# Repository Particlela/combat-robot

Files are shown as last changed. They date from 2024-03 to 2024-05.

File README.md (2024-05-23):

# combat-robot
# Robot_version_1.0
## 代码思路
基础运动底层模块写在move.c文件中(包含了对应函数)
巡线转弯等复杂模块写在game.c文件中
通过数组确定运动逻辑
该代码为电池电量较充足时可以较好地完成拿3分的任务,预赛因电量变化出现误差
### 灰度传感器
始终都要工作，通过gpio口发送信息给主板进行处理，以达到巡线目的
### 接口
PE7-11被设置为五个灰度传感器的信号输入(高电平1 低电平0)
PE7接R2 橙色
PE8接R1 黄色
PE9接M 绿色
PE10接L1 蓝色
PE11接L2 紫色
要接5V和GND接口供电

### 差速两轮驱动小车
用了定时器从模式，频率为10kHz，TIM2主 TIM3 TIM4从
#### 接口
PD2对应IN1(白色)  PD3对应IN2(灰色)  IN1高IN2低左电机正转反之反转
PD0对应IN3(紫色)  PD1对应IN4(蓝色)  IN3高IN4低右电机正转反之反转
PA6接通道A(黑色)  PD12接通道B(绿色)
右轮 棕色上黑色下
左轮 紫色上蓝色下

#### 调试
**读转速要让定时器进入编码器模式**
接5V GND(L298N) 两个GPIO口(两个轮子都要)
50是最低极限
巡航占空比为88
#### 转速
TIM1(左)和TIM8(右)开编码器模式
TIM6计时10ms,每10ms读一次数据，最后输出转速
520B编码器:绿接地 蓝接3.3V 黄白连在(暂时不知道顺序)

### 舵机控制钳子
控制舵机可以只使用一个PWM信号，因为两个舵机只需要相对角度确定即可(TIM9)
#### 接口
接两个5V(红色) GND(棕色) PE6(左黄色) PE5(右黄色)

### 看门狗
防止出现故障却停不下的问题
1s重启一次,需要一直喂狗,注意关注能否每1s内能够喂狗
version1.0中删除了这一功能,因为开发者未能很好的使看门狗达到预期效果

### 蓝牙模块
用于发送代码进行调试
用TIM5确保非阻塞运行,频率为1Hz
暂时无法使用
#### 接口
接板子上写了USART2的四个接口

### 串口
目前使用串口收发数据,每50ms发送一次信息

### 断电与供电
长按key0断电,reset重启
key1将在校赛中有新的规划

## 算法
运用数组确定运动逻辑
通过调参实际测试确定参数,保证巡线与转弯准度
暂未实现PID控制算法
暂未实现读取电机转速
暂未修改车底板及设计(初步想法为框住物块,这样在运动中同时打乱空心圆柱位置)

# Robot_version_2.0
# Robot
## 代码思路
基础运动底层模块写在move.c文件中(包含了对应函数) 巡线转弯等复杂模块写在game.c文件中 通过数组确定运动逻辑 该代码为电池电量较充足时可以较好地完成拿3分的任务,预赛因电量变化出现误差
### 灰度传感器
始终都要工作，通过gpio口发送信息给主板进行处理，以达到巡线目的
### 接口
PE7-11被设置为五个灰度传感器的信号输入(高电平1 低电平0)
PE7接R2 紫色
PE8接R1 蓝色
PE9接M 绿色
PE10接L1 黄色
PE11接L2 橙色
要接5V和GND接口供电

### 差速两轮驱动小车
用了定时器从模式，频率为10kHz，TIM2主 TIM3 TIM4从
#### 接口
PD2对应IN1(红色)  PD3对应IN2(橙色)  IN1高IN2低左电机正转反之反转
PD0对应IN3(黄色)  PD1对应IN4(绿色)  IN3高IN4低右电机正转反之反转
PA6接通道A(棕色)  PD12接通道B(蓝色)
右轮 棕色上黑色下
左轮 紫色上蓝色下

#### 调试
**读转速要让定时器进入编码器模式**
接5V GND(L298N) 两个GPIO口(两个轮子都要)
50是最低极限 巡航占空比为88

#### 转速
TIM1(左)和TIM8(右)开编码器模式
TIM6计时10ms,每10ms读一次数据，最后输出转速
520B编码器:绿接地 蓝接3.3V 本版本为连在无输出的接口

### 舵机控制钳子
控制舵机可以只使用一个PWM信号，因为两个舵机只需要相对角度确定即可(TIM9)
#### 接口
接两个5V(红色) GND(棕色) PE5(左黄色) PE6(右黄色)

### 蓝牙模块
用于发送代码进行调试
用TIM5确保非阻塞运行，频率为1Hz
#### 接口
接板子上写了USART2的那四个接口

### 串口
目前使用串口收发数据,每50ms发送一次信息

### 断电与供电
长按key0断电,reset重启 按下key1调整路径

## 算法
运用数组确定运动逻辑 通过调参实际测试确定参数,保证巡线与转弯准度
目前为二维数组，储存不同的路径
*(初步想法为框住物块,这样在运动中同时打乱空心圆柱位置)*
已修改，目前为框住物块并在万向轮前设有挡板

## 改进
姿态调整能否使用递归确保能够调整至理想状态，避免使用PID并完成读转速？*未实现*

# Robot_version_3.14
有时间就写！

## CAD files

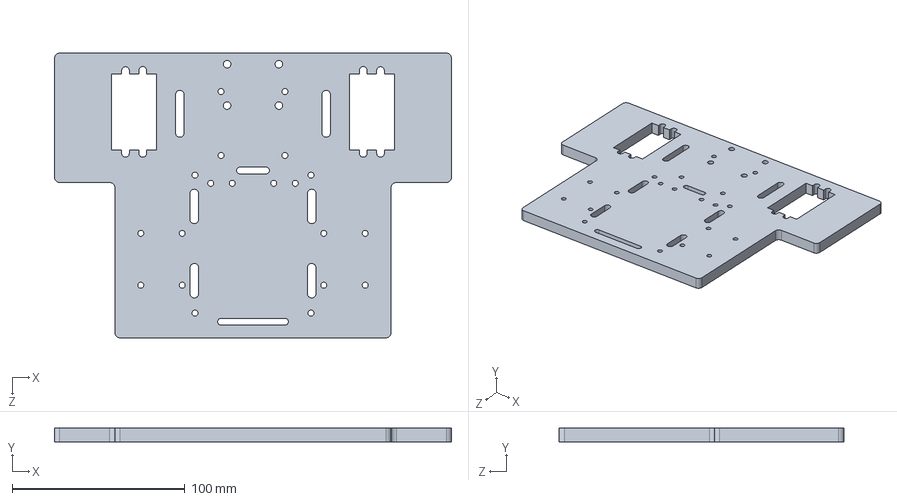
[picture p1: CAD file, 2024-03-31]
3D.SLDPRT
230.0 x 8.00 x 165.0 mm

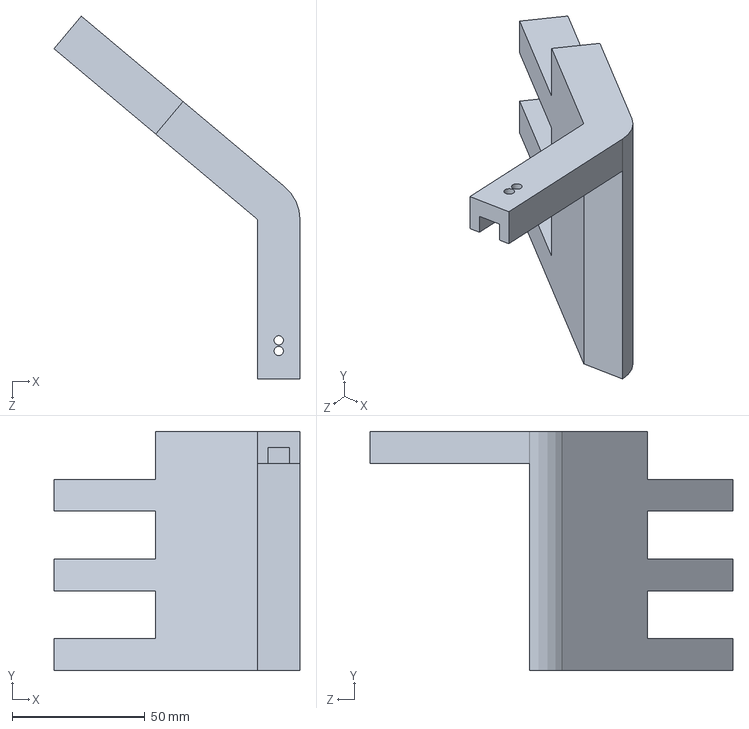
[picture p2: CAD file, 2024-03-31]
right.SLDPRT
92.6 x 90.0 x 136.5 mm

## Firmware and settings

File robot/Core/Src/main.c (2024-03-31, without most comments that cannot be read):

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
/* Includes ------------------------------------------------------------------*/
#include "main.h"
#include "dma.h"
#include "tim.h"
#include "usart.h"
#include "gpio.h"

/* USER CODE BEGIN Includes */
#include "move.h"
#include "game.h"
#include <math.h>
#include <stdio.h>
#include <string.h>
#include <stdlib.h>
/* USER CODE END Includes */


/* USER CODE BEGIN PV */
uint8_t TransmitData[200];
float MotorData = 0.0;//舵机的角度（左至右）
int EngineData[2] = {0,0};
int Data[200];


int cross_cnt = 0;
/* USER CODE END PV */

void SystemClock_Config(void);
/* USER CODE BEGIN 0 */
void HAL_TIM_PeriodElapsedCallback(TIM_HandleTypeDef *htim)
{
    if (htim->Instance == htim5.Instance)
    {
        MotorData = Motor_angel;

    	sprintf((char*)TransmitData, "灰度传感器：%d %d %d %d %d \n 已经经过%d个路口\n ", GrayData[0],GrayData[1],GrayData[2],GrayData[3],GrayData[4],cross_cnt);
    	HAL_UART_Transmit_DMA(&huart2, TransmitData, sizeof(TransmitData));//蓝牙
    	HAL_UART_Transmit_DMA(&huart3, TransmitData, sizeof(TransmitData));//传输信息
    }

    if(htim->Instance == htim6.Instance)		              //10ms中断
    {
        EngineData[0] = Read_Rotational_Speed(0);
        EngineData[1] = Read_Rotational_Speed(1);         //1为右，转速单位为RPM
        if(HAL_GPIO_ReadPin(Gray_L2_GPIO_Port, Gray_L2_Pin) == GPIO_PIN_SET)
        {
        	GrayData[0] = 1;
        }
        else if(HAL_GPIO_ReadPin(Gray_L2_GPIO_Port, Gray_L2_Pin) == GPIO_PIN_RESET)
        {
        	GrayData[0] = 0;
        }
        if(HAL_GPIO_ReadPin(Gray_L1_GPIO_Port, Gray_L1_Pin) == GPIO_PIN_SET)
        {
        	GrayData[1] = 1;
        }
        else if(HAL_GPIO_ReadPin(Gray_L1_GPIO_Port, Gray_L1_Pin) == GPIO_PIN_RESET)
        {
        	GrayData[1] = 0;
        }
        if(HAL_GPIO_ReadPin(Gray_M_GPIO_Port, Gray_M_Pin) == GPIO_PIN_SET)
        {
        	GrayData[2] = 1;
        }
        else if(HAL_GPIO_ReadPin(Gray_M_GPIO_Port, Gray_M_Pin) == GPIO_PIN_RESET)
        {
        	GrayData[2] = 0;
        }
        if(HAL_GPIO_ReadPin(Gray_R1_GPIO_Port, Gray_R1_Pin) == GPIO_PIN_SET)
        {
        	GrayData[3] = 1;
        }
        else if(HAL_GPIO_ReadPin(Gray_R1_GPIO_Port, Gray_R1_Pin) == GPIO_PIN_RESET)
        {
        	GrayData[3] = 0;
        }
        if(HAL_GPIO_ReadPin(Gray_R2_GPIO_Port, Gray_R2_Pin) == GPIO_PIN_SET)
        {
        	GrayData[4] = 1;
        }
        else if(HAL_GPIO_ReadPin(Gray_R2_GPIO_Port, Gray_R2_Pin) == GPIO_PIN_RESET)
        {
        	GrayData[4] = 0;
        }
    }
	else if(htim->Instance == htim1.Instance)
	{
		if(COUNTERNUMLEFT < 10000)	EngineLeft.loopNum++;         //向上计数超过10000，正溢出+1
		else if(COUNTERNUMLEFT > 10000)	EngineLeft.loopNum--;     //向下计数小于0，负溢出+1
		__HAL_TIM_SetCounter(&htim1, 10000);
	}
	else if(htim->Instance == htim8.Instance)
	{
		if(COUNTERNUMRIGHT < 10000)	EngineRight.loopNum++;         //向上计数超过10000，正溢出+1
		else if(COUNTERNUMRIGHT > 10000)	EngineRight.loopNum--;     //向下计数小于0，负溢出+1
		__HAL_TIM_SetCounter(&htim8, 10000);
	}
}

/* USER CODE END 0 */

/**
  * @brief  The application entry point.
  * @retval int
  */
int main(void)
{

  /* MCU Configuration--------------------------------------------------------*/

  /* Reset of all peripherals, Initializes the Flash interface and the Systick. */
  HAL_Init();

  /* Configure the system clock */
  SystemClock_Config();

  /* Initialize all configured peripherals */
  MX_GPIO_Init();
  MX_DMA_Init();
  MX_TIM9_Init();
  MX_TIM2_Init();
  MX_TIM3_Init();
  MX_TIM4_Init();
  MX_USART2_UART_Init();
  MX_TIM5_Init();
  MX_TIM1_Init();
  MX_TIM6_Init();
  MX_TIM8_Init();
  MX_USART3_UART_Init();
  /* USER CODE BEGIN 2 */
  Engine_Init();
  Motor_Init();
  GraySensor_Init();
  HAL_TIM_Base_Start_IT(&htim5);//初始化TIM5，用于发送非阻塞信息

  HAL_Delay(3000);
  Motor_Position(2);

  int path[30] = {3, 3, 2, 3, 3, 1, 3, 3, 1, 3, 3, 0};
  /* USER CODE END 2 */

  /* Infinite loop */
  /* USER CODE BEGIN WHILE */
  while (1)
  {
	  if(path[cross_cnt] == 0){
		  Move_Twin_Wheels(-70, -70);
	      HAL_Delay(310);
		  Move_Twin_Wheels(0, 0);
		  while(1);
	  }else if(path[cross_cnt] == 1){
		  Move_Turn(1);
		  Position_Adj(1);
		  Motor_Position(2);

		  cross_cnt++;
		  for(int i = 0; i < 20; i++){
			  Move_Straight(1);
		  }
	  }else if(path[cross_cnt] == 2){
		  Move_Turn(2);
		  Position_Adj(2);
		  Motor_Position(2);

		  cross_cnt++;
		  for(int i = 0; i < 20; i++){
			  Move_Straight(1);
		  }
	  }else if(path[cross_cnt] == 3){
		  Move_Straight(1);
	  }

	  if(Judge_cross() == 1){
		  cross_cnt++;
          HAL_Delay(100);
	  }

      if(HAL_GPIO_ReadPin(GPIOE, GPIO_PIN_4) == GPIO_PIN_RESET)
      {
          HAL_Delay(50);
          if(HAL_GPIO_ReadPin(GPIOE, GPIO_PIN_4) == GPIO_PIN_RESET)
          {
        	  HAL_PWR_EnterSTANDBYMode();
        	  break;
          }
      }

    /* USER CODE END WHILE */

    /* USER CODE BEGIN 3 */
  }
  /* USER CODE END 3 */
}

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


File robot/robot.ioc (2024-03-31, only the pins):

Mcu.UserName=STM32F407VETx
PA13.Signal=SYS_JTMS-SWDIO
PA14.Signal=SYS_JTCK-SWCLK
PA2.GPIO_Label=BLE_TX
PA2.Signal=USART2_TX
PA3.GPIO_Label=BLE_RX
PA3.Signal=USART2_RX
PA6.GPIO_Label=Engine_PWM_Left
PA6.Signal=S_TIM3_CH1
PA8.GPIO_Label=Engine_Leftcode1
PA8.Signal=S_TIM1_CH1
PA9.GPIO_Label=Engine_Leftcode2
PA9.Signal=S_TIM1_CH2
PB10.Signal=USART3_TX
PB11.Signal=USART3_RX
PB3.GPIO_Label=Engine_Left_Green
PB3.Signal=GPIO_Input
PB5.GPIO_Label=Engine_Left_Yellow
PB5.Signal=GPIO_Input
PC0.GPIO_Label=Engine_Right_Yellow
PC0.Signal=GPIO_Input
PC1.GPIO_Label=Engine_Right_Green
PC1.Signal=GPIO_Input
PC6.GPIO_Label=Engine_Rightcode1
PC6.Signal=S_TIM8_CH1
PC7.GPIO_Label=Engine_Rightcode2
PC7.Signal=S_TIM8_CH2
PD0.GPIO_Label=Engine_Right2
PD0.Signal=GPIO_Output
PD1.GPIO_Label=Engine_Right1
PD1.Signal=GPIO_Output
PD12.GPIO_Label=Engine_PWM_Right
PD12.Signal=S_TIM4_CH1
PD2.GPIO_Label=Engine_Left2
PD2.Signal=GPIO_Output
PD3.GPIO_Label=Engine_Left1
PD3.Signal=GPIO_Output
PE10.GPIO_Label=Gray_L1
PE10.Signal=GPIO_Input
PE11.GPIO_Label=Gray_L2
PE11.Signal=GPIO_Input
PE4.Signal=GPIO_Input
PE5.GPIO_Label=Motor_PWM_TIM9_CH1
PE5.Signal=S_TIM9_CH1
PE6.GPIO_Label=Motor_PWM_TIM9_CH2
PE6.Signal=S_TIM9_CH2
PE7.GPIO_Label=Gray_R2
PE7.Signal=GPIO_Input
PE8.GPIO_Label=Gray_R1
PE8.Signal=GPIO_Input
PE9.GPIO_Label=Gray_M
PE9.Signal=GPIO_Input
PH0-OSC_IN.Signal=RCC_OSC_IN
PH1-OSC_OUT.Signal=RCC_OSC_OUT

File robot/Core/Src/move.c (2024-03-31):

/*
 * move.c
 *
 *  Created on: Mar 15, 2024
 *      Author: 高恒斌
 */

#include <math.h>
#include <stdio.h>
#include <string.h>
#include <stdlib.h>
#include "move.h"
#include "main.h"
#include "dma.h"
#include "tim.h"
#include "usart.h"
#include "gpio.h"

int GrayData[5]={0};//这5个变量用于算法中使用的灰度传感器的状态 0-L2 1-L1 2-M 3-R1 4-R2
int MoveSituation = 0;//0代表直行，1代表转弯或后退，2代表左转，3代表右转，4代表后退  MoveSituation改变后首先要HAL_TIM_PWM_Stop( , );
float Motor_angel = 0;//舵机角度
Engine EngineLeft;
Engine EngineRight;

//TIM3左轮 TIM4右轮
void Move_Left(int velocity)
{
		if(velocity >= 0){
			HAL_GPIO_WritePin(Engine_Left1_GPIO_Port, Engine_Left1_Pin, GPIO_PIN_SET);
			HAL_GPIO_WritePin(Engine_Left2_GPIO_Port, Engine_Left2_Pin, GPIO_PIN_RESET);
		    __HAL_TIM_SET_COMPARE(&htim3, TIM_CHANNEL_1, velocity);
		}
		else if(velocity < 0){
			HAL_GPIO_WritePin(Engine_Left1_GPIO_Port, Engine_Left1_Pin, GPIO_PIN_RESET);
			HAL_GPIO_WritePin(Engine_Left2_GPIO_Port, Engine_Left2_Pin, GPIO_PIN_SET);
		    __HAL_TIM_SET_COMPARE(&htim3, TIM_CHANNEL_1, -1*velocity);
		}
}

void Move_Right(int velocity)
{
		if(velocity >= 0){
			HAL_GPIO_WritePin(Engine_Right1_GPIO_Port, Engine_Right1_Pin, GPIO_PIN_SET);
			HAL_GPIO_WritePin(Engine_Right2_GPIO_Port, Engine_Right2_Pin, GPIO_PIN_RESET);
		    __HAL_TIM_SET_COMPARE(&htim4, TIM_CHANNEL_1, velocity);
		}
		else if(velocity < 0){
			HAL_GPIO_WritePin(Engine_Right1_GPIO_Port, Engine_Right1_Pin, GPIO_PIN_RESET);
			HAL_GPIO_WritePin(Engine_Right2_GPIO_Port, Engine_Right2_Pin, GPIO_PIN_SET);
		    __HAL_TIM_SET_COMPARE(&htim4, TIM_CHANNEL_1, -1*velocity);
		}
}
//分别控制左右轮 velocity 范围 -100 - -50  50 - 100

void Move_Twin_Wheels(int velocity_1 ,int velocity_2)
{
	Move_Left(velocity_2);
	Move_Right(velocity_1);
}
//velocity_1 是左轮， velocity_2 是右轮
//这里存在错误！Left Right 反了！但是上面那行注释正确
//65， 63几乎直行（偏右）

float Read_Rotational_Speed(int n)
{
	float rotational_speed = 0;
	if(n == 0)
	{
		int16_t pluse = COUNTERNUMLEFT - RELOADVALUELEFT/2;
        //从开始到现在当前10ms的总脉冲数
		EngineLeft.totalAngle = pluse + EngineLeft.loopNum * RELOADVALUELEFT/2;
        //进行速度计算,4倍频,编码器11位,减速比56,再乘以6000即为每分钟输出轴多少转
        //motor.totalAngle - motor.lastAngle为当前10ms内的增量，即脉冲数
		EngineLeft.speed = (float)(EngineLeft.totalAngle - EngineLeft.lastAngle)/(4*11*RR)*6000;
		rotational_speed = EngineLeft.speed;
		EngineLeft.lastAngle = EngineLeft.totalAngle;              //更新转过的圈数
		return rotational_speed;
	}

    //如果是编码器更新中断,即10ms内,脉冲数超过了计数范围,需要进行处理
	else if(n == 1)
	{
		int16_t pluse = COUNTERNUMRIGHT - RELOADVALUERIGHT/2;
        //从开始到现在当前10ms的总脉冲数
		EngineRight.totalAngle = pluse + EngineRight.loopNum * RELOADVALUERIGHT/2;
        //进行速度计算,4倍频,编码器11位,减速比56,再乘以6000即为每分钟输出轴多少转
        //motor.totalAngle - motor.lastAngle为当前10ms内的增量，即脉冲数
		EngineRight.speed = (float)(EngineRight.totalAngle - EngineRight.lastAngle)/(4*11*RR)*6000;
		rotational_speed = EngineRight.speed;
		EngineRight.lastAngle = EngineRight.totalAngle;              //更新转过的圈数
		return rotational_speed;
	}
	else
		return 0;
}
//n=0读左轮转速，n=1读右轮转速


void Motor_Control(int duty_cycle)
{
    // 舵机控制占空比范围2.5% ~ 12.5%
    // Counter Period设置的是2000，因此占空比设置范围是50 ~ 250
	Motor_angel = duty_cycle * 0.9 - 45;
    __HAL_TIM_SET_COMPARE(&htim9, TIM_CHANNEL_1, 50 + duty_cycle);
    __HAL_TIM_SET_COMPARE(&htim9, TIM_CHANNEL_2, 250 - duty_cycle);
}
//要先初始化再装在车上
//50-250表示0-180度，duty_cycle的范围是0-200
//输入0为初始状态（完全张开），输入65为完全收缩，输入35为装载物块后的收紧值

void Engine_Init()
{

	HAL_TIM_Encoder_Start(&htim1, TIM_CHANNEL_ALL);      //开启编码器定时器
    __HAL_TIM_ENABLE_IT(&htim1,TIM_IT_UPDATE);           //开启编码器定时器更新中断,防溢出处理
	HAL_TIM_Encoder_Start(&htim8, TIM_CHANNEL_ALL);
    __HAL_TIM_ENABLE_IT(&htim8,TIM_IT_UPDATE);
	HAL_TIM_Base_Start_IT(&htim6);                       //开启10ms定时器中断
	HAL_TIM_PWM_Start_IT(&htim3, TIM_CHANNEL_1);
	HAL_TIM_PWM_Start_IT(&htim4, TIM_CHANNEL_1);
	__HAL_TIM_SET_COUNTER(&htim1, 10000);
	__HAL_TIM_SET_COUNTER(&htim8, 10000);
	EngineLeft.loopNum = 0;
	EngineRight.loopNum = 0;
	Move_Twin_Wheels(0, 0);
}


void Motor_Init()
{
	HAL_TIM_PWM_Start_IT(&htim9, TIM_CHANNEL_1);
	HAL_TIM_PWM_Start_IT(&htim9, TIM_CHANNEL_2);
	Motor_Control(65);
	HAL_Delay(1000);
}
//延时0.8s保证姿态调整正常

void GraySensor_Init()
{
	GrayData[0] = 0;
	GrayData[1] = 0;
	GrayData[2] = 0;
	GrayData[3] = 0;
	GrayData[4] = 0;
}

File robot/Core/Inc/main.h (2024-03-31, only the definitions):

#define Motor_PWM_TIM9_CH1_Pin GPIO_PIN_5
#define Motor_PWM_TIM9_CH1_GPIO_Port GPIOE
#define Motor_PWM_TIM9_CH2_Pin GPIO_PIN_6
#define Motor_PWM_TIM9_CH2_GPIO_Port GPIOE
#define Engine_Right_Yellow_Pin GPIO_PIN_0
#define Engine_Right_Yellow_GPIO_Port GPIOC
#define Engine_Right_Green_Pin GPIO_PIN_1
#define Engine_Right_Green_GPIO_Port GPIOC
#define BLE_TX_Pin GPIO_PIN_2
#define BLE_TX_GPIO_Port GPIOA
#define BLE_RX_Pin GPIO_PIN_3
#define BLE_RX_GPIO_Port GPIOA
#define Engine_PWM_Left_Pin GPIO_PIN_6
#define Engine_PWM_Left_GPIO_Port GPIOA
#define Gray_R2_Pin GPIO_PIN_7
#define Gray_R2_GPIO_Port GPIOE
#define Gray_R1_Pin GPIO_PIN_8
#define Gray_R1_GPIO_Port GPIOE
#define Gray_M_Pin GPIO_PIN_9
#define Gray_M_GPIO_Port GPIOE
#define Gray_L1_Pin GPIO_PIN_10
#define Gray_L1_GPIO_Port GPIOE
#define Gray_L2_Pin GPIO_PIN_11
#define Gray_L2_GPIO_Port GPIOE
#define Engine_PWM_Right_Pin GPIO_PIN_12
#define Engine_PWM_Right_GPIO_Port GPIOD
#define Engine_Rightcode1_Pin GPIO_PIN_6
#define Engine_Rightcode1_GPIO_Port GPIOC
#define Engine_Rightcode2_Pin GPIO_PIN_7
#define Engine_Rightcode2_GPIO_Port GPIOC
#define Engine_Leftcode1_Pin GPIO_PIN_8
#define Engine_Leftcode1_GPIO_Port GPIOA
#define Engine_Leftcode2_Pin GPIO_PIN_9
#define Engine_Leftcode2_GPIO_Port GPIOA
#define Engine_Right2_Pin GPIO_PIN_0
#define Engine_Right2_GPIO_Port GPIOD
#define Engine_Right1_Pin GPIO_PIN_1
#define Engine_Right1_GPIO_Port GPIOD
#define Engine_Left2_Pin GPIO_PIN_2
#define Engine_Left2_GPIO_Port GPIOD
#define Engine_Left1_Pin GPIO_PIN_3
#define Engine_Left1_GPIO_Port GPIOD
#define Engine_Left_Green_Pin GPIO_PIN_3
#define Engine_Left_Green_GPIO_Port GPIOB
#define Engine_Left_Yellow_Pin GPIO_PIN_5
#define Engine_Left_Yellow_GPIO_Port GPIOB

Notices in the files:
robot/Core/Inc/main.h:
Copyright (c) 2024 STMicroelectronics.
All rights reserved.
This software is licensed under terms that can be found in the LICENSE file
